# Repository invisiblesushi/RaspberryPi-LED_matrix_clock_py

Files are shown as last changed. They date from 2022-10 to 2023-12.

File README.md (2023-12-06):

# RaspberryPi-LED_matrix_clock_py 🕰️🌸

A Raspberry Pi-based LED matrix clock with additional features.

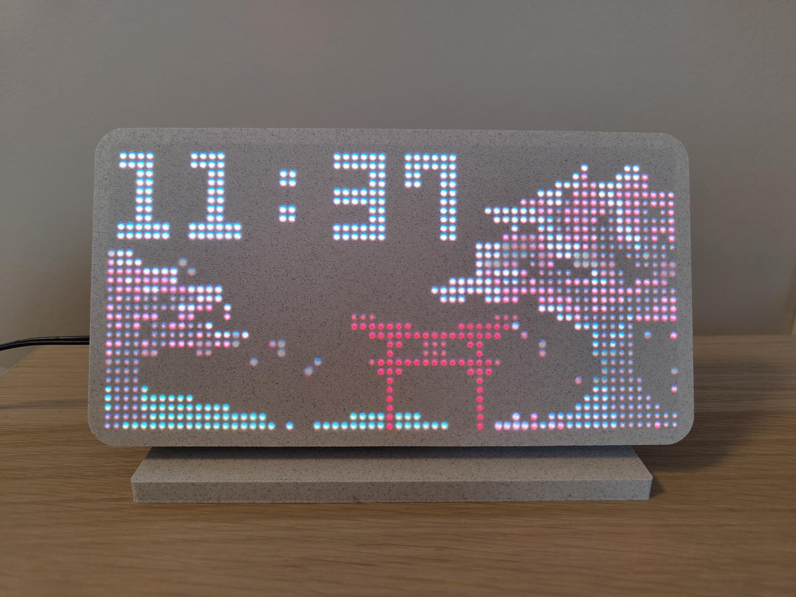
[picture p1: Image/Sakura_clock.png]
Sakura Clock

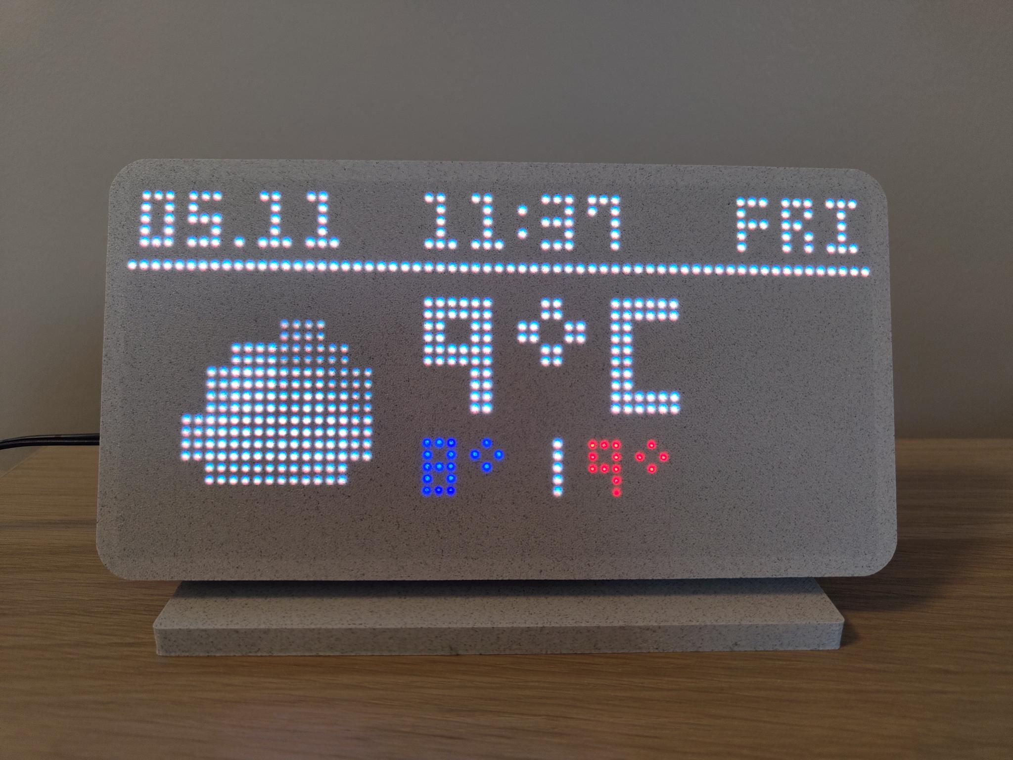
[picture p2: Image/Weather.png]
Weather Display

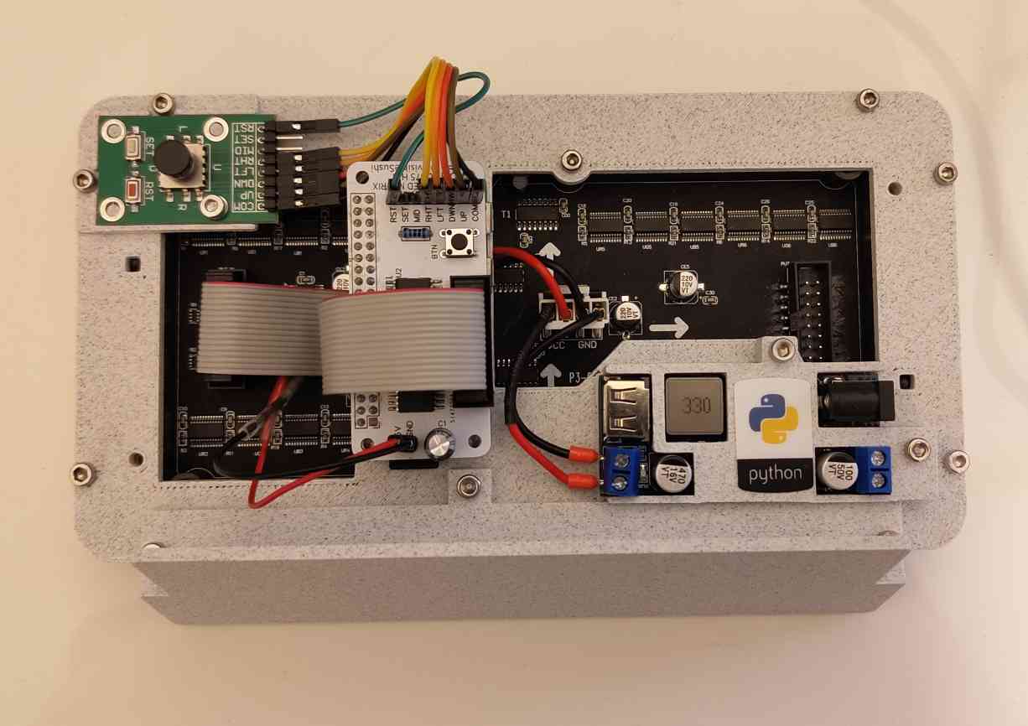
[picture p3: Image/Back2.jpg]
Back Image


## Setup Python 3

```bash
git clone https://github.com/hzeller/rpi-rgb-led-matrix.git
cd /bindings/python/
sudo make build-python PYTHON=$(which python3)
sudo make install-python PYTHON=$(which python3)

# Make sure rgbmatrix folder exists in /usr/local/lib/python3.9/dist-packages/rgbmatrix

```

# Requirement
- PIL
- pyowm
- https://github.com/hzeller/rpi-rgb-led-matrix libary

# Part list
- Raspberry pi zero W
- HCW-P715 Buck Converter
- P3 RGB 64x32 dot panel
- Five Direction Navigation Button Module

# GPIO conncetion
| LED matrix pin | Pin | Pin |LED matrix pin
|---:|:---:|:---:|:---
| btn_com + [resistor] | 1 | 2 | -
| - | 3 | 4 | -
| - | 5 | 6 | **GND**
| **strobe/latch** | 7 | 8 |  btn_down [screen - 1]
| - | 9 |  10 |  btn_up [screen + 1]
| **clock** |  11 |  12 | **OE-**  
| **G1** |  13 |  14 | -
| **A** |  15 |  16 | **B** 
| - |  17 |  18 | **C** 
| **B2** |  19 |  20 | -
| **G2** |  21 |  22 | **D** 
| **R1** |  23 |  24 | **R2**
| - |  25 |  26 | **B1**
| - |  27 |  28 | -
| - |  29 |  30 | -
| btn_rst [Shutdown] |  31 |  32 | btn_right  [brightness - 1]
| btn_left [brightness + 1] |  33 |  34 | 
| - |  35 |  36 | -
| - |  37 |  38 | -
| - |  39 |  40 | -

# Run
```shell
// Disclamer it has to run as sudo, cause it's reqired by the libary used
sudo python main.py --led-no-hardware-pulse
```

# Autostart on startup
```shell
sudo nano .bashrc

Add line:
sudo /usr/bin/python /home/pi/RPI-led-matrix-clock-py/main.py >> /home/pi/log.txt
```

# Source
- sakura.png https://github.com/allenslab/matrix-dashboard/blob/master/impl/apps_v2/res/main_screen/sakura-bg.png
- tiny.otf https://github.com/allenslab/matrix-dashboard/blob/master/impl/fonts/tiny.otf

# Custom raspberry pi hat
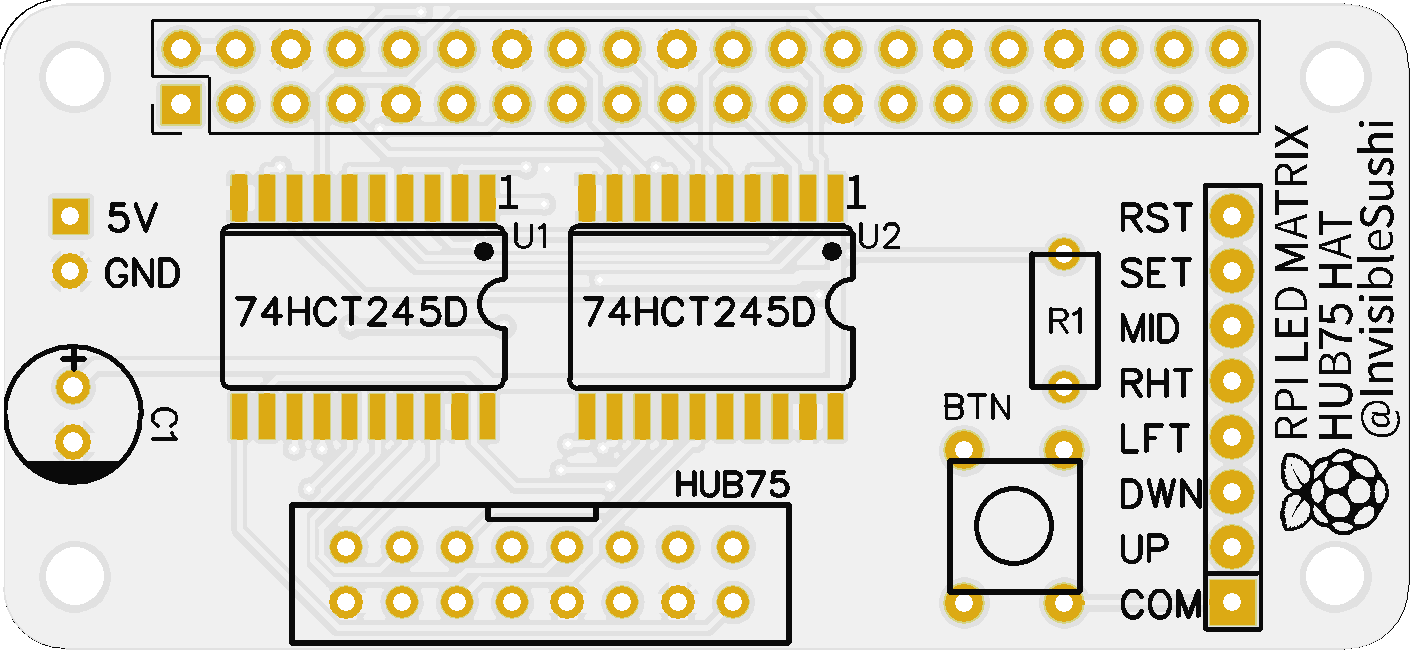
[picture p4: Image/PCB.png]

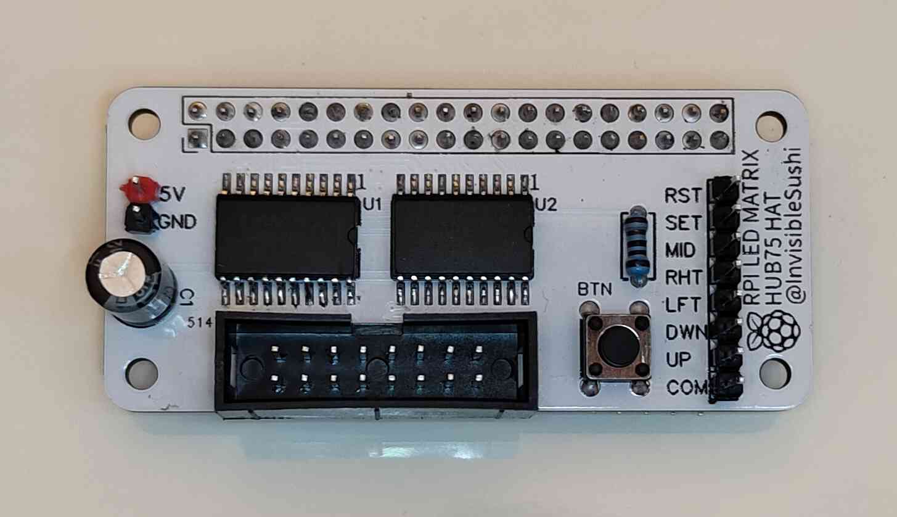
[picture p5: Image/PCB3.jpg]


# Schematics
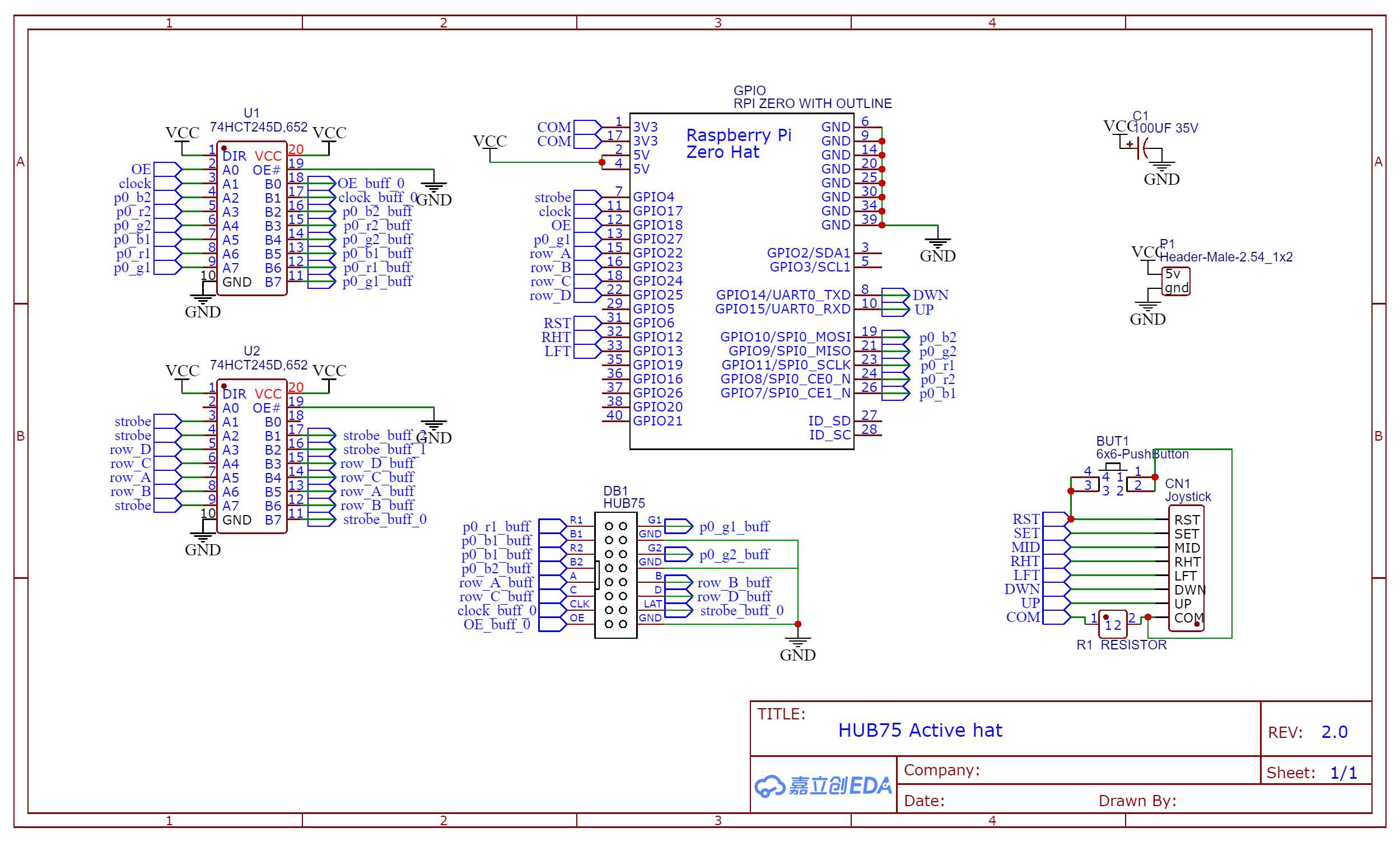
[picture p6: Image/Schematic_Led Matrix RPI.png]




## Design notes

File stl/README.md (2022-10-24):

# Print settings
- First layer 0.2mm
- Print height 0.3
- Infill 15%
- Material PLA

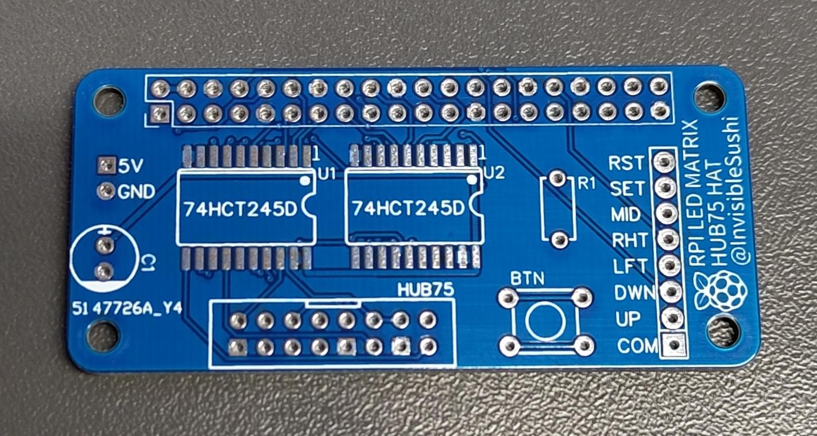
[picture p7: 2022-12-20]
Image/PCB2.png

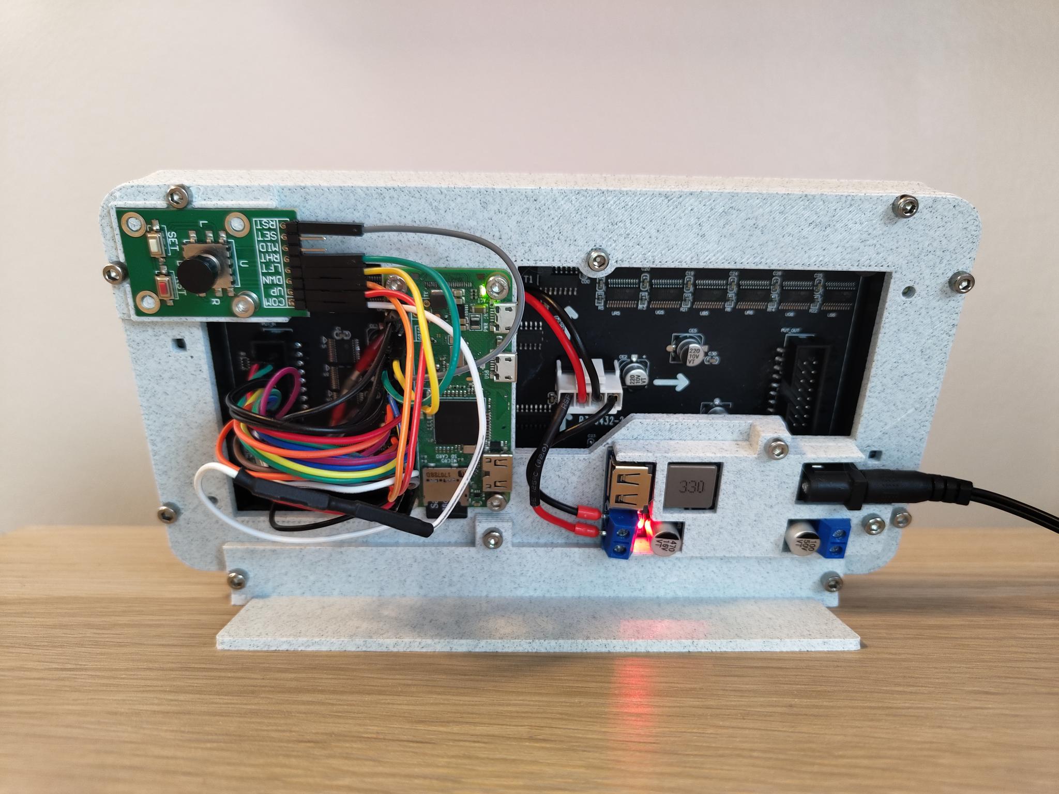
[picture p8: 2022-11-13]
Image/Back.png

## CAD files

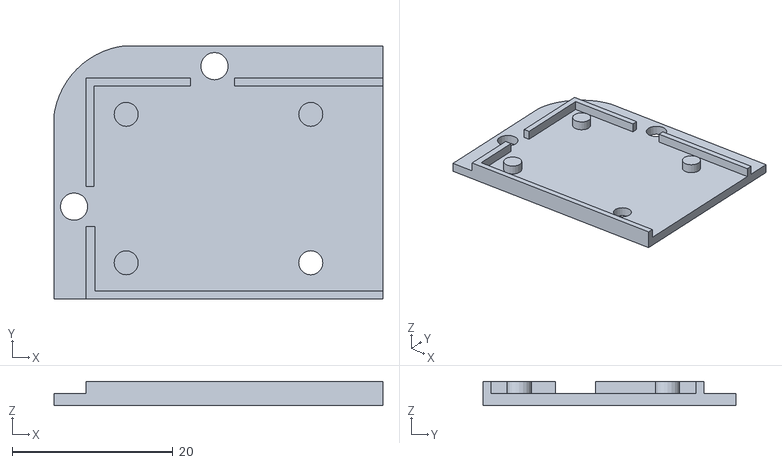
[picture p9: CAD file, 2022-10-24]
stl/joysticmount.stl
41.0 x 31.5 x 3.00

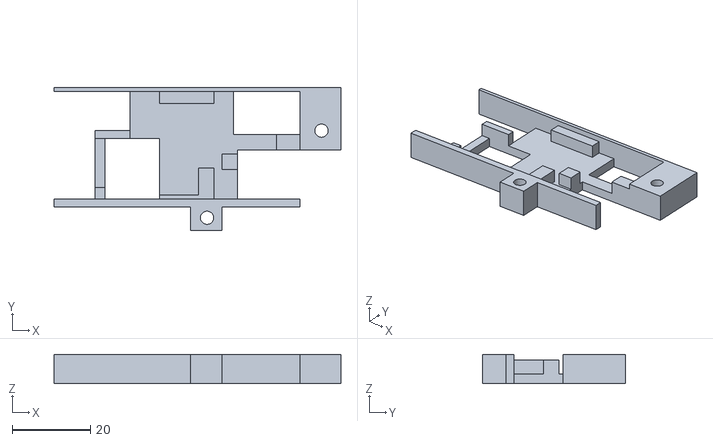
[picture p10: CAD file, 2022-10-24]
stl/psu_mount.stl
73.5 x 36.5 x 7.50

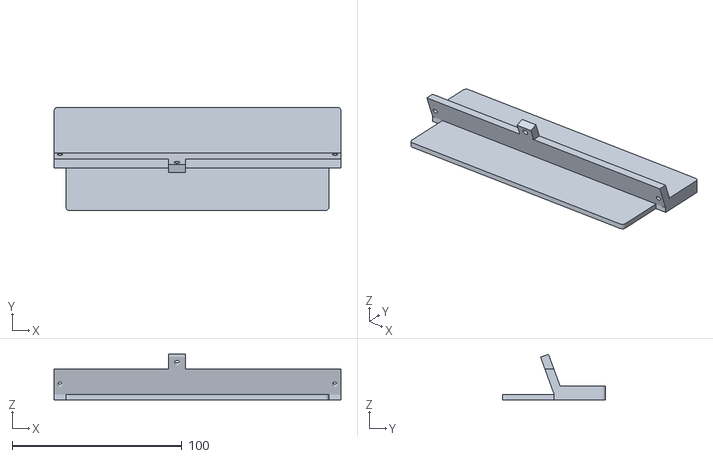
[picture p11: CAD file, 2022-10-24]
stl/Feet.stl
169.1 x 60.9 x 26.8

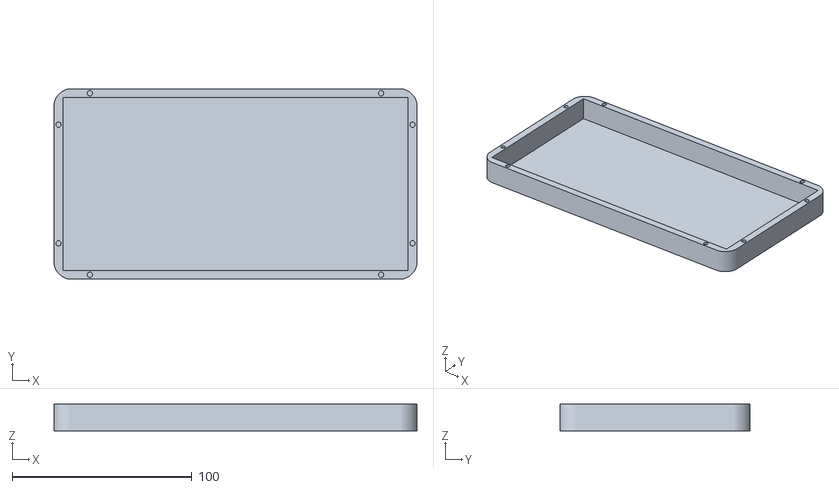
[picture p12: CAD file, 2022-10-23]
stl/front.stl
202.0 x 106.0 x 15.0

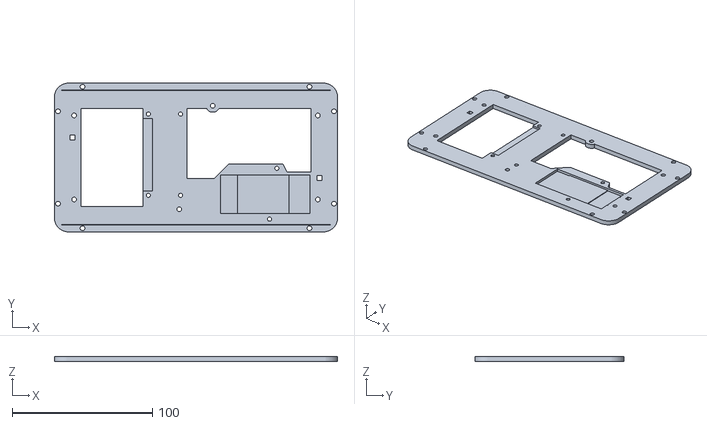
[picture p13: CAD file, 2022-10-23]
stl/back.stl
202.0 x 106.0 x 3.50

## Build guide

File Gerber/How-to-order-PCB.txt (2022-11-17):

How to Order PCB

Please refer to:
https://docs.easyeda.com/en/PCB/Order-PCB

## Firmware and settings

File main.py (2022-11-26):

from rgbmatrix import RGBMatrix, RGBMatrixOptions, graphics
from PIL import Image, ImageDraw, ImageFont
from datetime import datetime
from configparser import ConfigParser
from pyowm.owm import OWM
import RPi.GPIO as GPIO
import time
import os

#Globals
textColor = (255, 255, 255)
textColor_blue = (0, 0, 255)
textColor_red = (255, 0, 0)

matrix = None
weather = None
last_weather_time = datetime.min

image = Image.open("/home/pi/RPI-led-matrix-clock-py/res/black.png").convert("RGB")
image.thumbnail((64, 32), Image.Resampling.LANCZOS)
config = ConfigParser()
config.read('/home/pi/RPI-led-matrix-clock-py/appsettings.ini')

#GPIO pin config
screen_id = 0
screen_max = 3
btn_up = 10
btn_down = 8
btn_right = 32
btn_left = 33
btn_rst = 31
brightness = 100

def main():
	print('Starting : ' + str(datetime.now()))
	global matrix
	global weather
	weather = get_weather()
	matrix = matrix_init(brightness)
	gpio_init()

	print('screen_id = ' + str(screen_id))

	try:
		while True:  # Run forever
			currentTime = datetime.now()

			if screen_id == 0:
				frame = sakura_clock(matrix, currentTime)
			if screen_id == 1:
				frame = fuji_clock(matrix, currentTime)
			if screen_id == 2:
				frame = clock(matrix, currentTime)
			if screen_id == 3:
				frame = weather_clock(matrix, currentTime)

			time.sleep(0.1)

			# Print image on LED matrix
			matrix.SetImage(frame)

	finally:
		GPIO.cleanup
		print('GPIO.cleanup')


def matrix_init(brightness):
	options = RGBMatrixOptions()
	options.rows = 32
	options.cols = 64
	options.chain_length = 1
	options.parallel = 1
	options.hardware_mapping = 'regular'
	options.brightness = brightness
	options.gpio_slowdown = 0
	options.pwm_lsb_nanoseconds = 80
	options.limit_refresh_rate_hz = 150
	options.drop_privileges = False
	return RGBMatrix(options = options)

def gpio_init():
	GPIO.cleanup
	print('GPIO.cleanup')

	GPIO.setmode(GPIO.BOARD)
	GPIO.setwarnings(False)
	# Configure gpio buttons
	GPIO.setup(btn_up, GPIO.IN, pull_up_down=GPIO.PUD_DOWN)
	GPIO.setup(btn_down, GPIO.IN, pull_up_down=GPIO.PUD_DOWN)
	GPIO.setup(btn_right, GPIO.IN, pull_up_down=GPIO.PUD_DOWN)
	GPIO.setup(btn_left, GPIO.IN, pull_up_down=GPIO.PUD_DOWN)
	GPIO.setup(btn_rst, GPIO.IN, pull_up_down=GPIO.PUD_DOWN)

	# Set button event detection
	GPIO.add_event_detect(btn_up, GPIO.RISING, callback=on_pushup, bouncetime=200)
	GPIO.add_event_detect(btn_down, GPIO.RISING, callback=on_pushdown, bouncetime=200)
	GPIO.add_event_detect(btn_right, GPIO.RISING, callback=on_pushright, bouncetime=200)
	GPIO.add_event_detect(btn_left, GPIO.RISING, callback=on_pushleft, bouncetime=200)
	GPIO.add_event_detect(btn_rst, GPIO.RISING, callback=on_pushrst, bouncetime=200)

def on_pushup(channel):
	global screen_id
	if screen_id >= screen_max:
		screen_id = 0
	else:
		screen_id = screen_id + 1
	print('screen_id = ' + str(screen_id))

def on_pushdown(channel):
	global screen_id
	if screen_id <= 0:
		screen_id = 3
	else:
		screen_id = screen_id - 1
	print('screen_id = ' + str(screen_id))

def on_pushright(channel):
	global matrix
	global brightness
	if (brightness <= 100) & (brightness > 10):
		brightness = brightness - 10
	print(brightness)
	matrix.brightness = brightness

def on_pushleft(channel):
	global matrix
	global brightness
	if (brightness >= 10) & (brightness < 100):
		brightness = brightness + 10
	print(brightness)
	matrix.brightness = brightness

def on_pushrst(channel):
	print("Shutting down")
	os.system("shutdown now -h")

def sakura_clock(matrix, currentTime):
	font = ImageFont.truetype(font='/home/pi/RPI-led-matrix-clock-py/fonts/tiny.otf', size=10)
	image = Image.open("/home/pi/RPI-led-matrix-clock-py/res/sakura.png").convert("RGB")
	frame = image.copy()
	draw = ImageDraw.Draw(frame)
	draw.text((1, 1), currentTime.strftime("%H:%M"), textColor, font)
	return frame

def fuji_clock(matrix, currentTime):
	font = ImageFont.truetype(font='/home/pi/RPI-led-matrix-clock-py/fonts/tiny.otf', size=10)
	image = Image.open("/home/pi/RPI-led-matrix-clock-py/res/fuji.png").convert("RGB")
	frame = image.copy()
	draw = ImageDraw.Draw(frame)
	draw.text((13, 1), currentTime.strftime("%H:%M"), textColor, font)
	return frame

def clock(matrix, currentTime):
	font = ImageFont.truetype(font='/home/pi/RPI-led-matrix-clock-py/fonts/tiny.otf', size=15)
	image = Image.open("/home/pi/RPI-led-matrix-clock-py/res/black.png").convert("RGB")
	frame = image.copy()
	draw = ImageDraw.Draw(frame)
	draw.text((4, 8.5), currentTime.strftime("%H:%M"), textColor, font)
	return frame

def weather_clock(matrix, currentTime):
	global weather
	font = ImageFont.truetype(font='/home/pi/RPI-led-matrix-clock-py/fonts/tiny.otf', size=10)
	font_small = ImageFont.truetype(font='/home/pi/RPI-led-matrix-clock-py/fonts/tiny.otf', size=5)
	weather = get_weather()

	weather_icon = get_weather_icon(weather.weather_icon_name)
	weatherIcon = Image.open(weather_icon).convert("RGB")
	image.paste(weatherIcon, (5,10))

	#Temperature Celcius
	celsius = weather.temperature('celsius')
	temperature = str(round(celsius['temp'])) + '°C'
	temperature_max = str(round(celsius['temp_max'])) + '°'
	temperature_min = str(round(celsius['temp_min'])) + '°'

	frame = image.copy()
	draw = ImageDraw.Draw(frame)

	# low high temp
	draw.text((25, 10), temperature, textColor, font)
	draw.text((25, 22), temperature_min, textColor_blue, font_small)
	draw.text((35, 22), '|', textColor, font_small)
	draw.text((39, 22), temperature_max, textColor_red, font_small)

	# Date
	draw.text((1, 1), currentTime.strftime('%d'), textColor, font_small)
	draw.line(((9, 5), (9, 5)), textColor, 1)
	draw.text((11, 1), currentTime.strftime('%m'), textColor, font_small)

	# Time
	draw.text((25, 1), currentTime.strftime('%H'), textColor, font_small)
	draw.text((32, 1), currentTime.strftime(':'), textColor, font_small)
	draw.text((35, 1), currentTime.strftime('%M'), textColor, font_small)

	# Weekday
	draw.text((52, 1), get_weekday_short(), textColor, font_small)

	# Divider line
	draw.line(((0,7), (64,7)), textColor, 1)

	return frame

def get_weather():
	global weather
	global last_weather_time
	last_weather_diff_min = (datetime.now() - last_weather_time).total_seconds() / 60

	# get weather every 10m
	if last_weather_diff_min > 10:
		try:
			owm = OWM(config.get('Open_weather_map', 'owm_api_key'))
			location = config.get('Open_weather_map', 'location')
			mgr = owm.weather_manager()
			weather = mgr.weather_at_place(location).weather
			last_weather_time = datetime.now()
			print('Weather = ' + str(weather))

		except:
			print("Could not get weather")

	return weather

def get_weekday_short():
	weekday = datetime.now().weekday()
	weekdays = {1: 'MON', 2: 'TUE', 3: 'WED', 4: 'THU', 5: 'FRI', 6: 'SAT', 7: 'SAT'}
	return weekdays.get(weekday)


def get_weather_icon(icon_name):
	icons = {
		'01d': "/home/pi/RPI-led-matrix-clock-py/res/01d.png",
		'01n': "/home/pi/RPI-led-matrix-clock-py/res/01d.png",
		'02d': "/home/pi/RPI-led-matrix-clock-py/res/02d.png",
		'02d': "/home/pi/RPI-led-matrix-clock-py/res/02d.png",
		'03d': "/home/pi/RPI-led-matrix-clock-py/res/03d.png",
		'03n': "/home/pi/RPI-led-matrix-clock-py/res/03d.png",
		'04d': "/home/pi/RPI-led-matrix-clock-py/res/04d.png",
		'04n': "/home/pi/RPI-led-matrix-clock-py/res/04d.png",
		'09d': "/home/pi/RPI-led-matrix-clock-py/res/09d.png",
		'09n': "/home/pi/RPI-led-matrix-clock-py/res/09d.png",
		'10d': "/home/pi/RPI-led-matrix-clock-py/res/10d.png",
		'10n': "/home/pi/RPI-led-matrix-clock-py/res/10d.png",
		'13d': "/home/pi/RPI-led-matrix-clock-py/res/13d.png",
		'13n': "/home/pi/RPI-led-matrix-clock-py/res/13d.png",
		'50d': "/home/pi/RPI-led-matrix-clock-py/res/50d.png",
		'50n': "/home/pi/RPI-led-matrix-clock-py/res/50d.png"
	}
	return icons.get(icon_name)


# Main function
if __name__== "__main__" :
	main()

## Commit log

2022-10-23 stl files, readme
    [back.stl, front.stl, psu_mount.stl]
2022-10-24 Updated stl
    [Feet.stl, psu_mount.stl]
2022-10-24 Added joystick
    GPIO Joystick control
    Change screen,
    Brightness adjust
    [joysticmount.stl]
2022-11-03 Added shutdown button
2022-11-17 Gerber files and schematics
    [Drill_NPTH_Through.DRL, Drill_PTH_Through.DRL, Drill_PTH_Through_Via.DRL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]
2022-12-03 New Active PCB design
    Active PCB design based on https://github.com/hzeller/rpi-rgb-led-matrix/tree/master/adapter/active-3
    Uses 74HCT245D to level shift signals from 3.3V to 5V.
    [Drill_NPTH_Through.DRL, Drill_PTH_Through.DRL, Drill_PTH_Through_Via.DRL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]
2022-12-20 Fixed PCB design error
    [Drill_NPTH_Through.DRL, Drill_PTH_Through.DRL, Drill_PTH_Through_Via.DRL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]
2023-01-04 Pcb images
